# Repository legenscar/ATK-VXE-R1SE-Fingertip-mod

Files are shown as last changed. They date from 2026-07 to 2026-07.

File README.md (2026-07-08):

# ATK-VXE-R1SE-Fingertip-mod
Fingertip Mouse mod for the ATK VXE R1SE+ PCB, featuring a flared pinky rest for a relaxed grip. Read through the whole README before starting.
  
## Things you will need: 
- a suitable screwdriver
- dot skates
- access to a 3D Printer or 3D Printing service
- Sanding paper (recommended but optional)
- Grip tape (recommended but optional)
- patience (recommended but optional)
- lighter (could come in handy)

## Assembly
### 1. Download and print all of the STL files.
I recommend rotating the main buttons 90 degrees if you are printing on a FDM to make sure they feel smooth. Dont forget the supports!



### 2. Disassemble the original mouse
Be careful not to rip the side PCB ribbons. Keep the screws and keep track of their mounting points. The printed mouse shell uses those exact screws with identical mounting points. You will also need to remove the screws for the main buttons.
  
### 3. Assemble the shell
First, screw the PCB onto the base. Dont forget to put the lense underneath first.

Base with PCB

Next, lets take care of the side PCB. For that, mount the side PCB onto the support frame as shown in the picture and insert the side buttons. You may need to sand the "leg" if they dont fit, or glue them into place if they are too lose. If you experience excessive pretravel apply some tape. 

Side PCB assembly

You will need to cut the little "tail" of the side PCB if you dont want it sticking out. I suggest you make that decision after you have assembled the whole mouse. 

Plug in the battery and stick it onto the sensor. Now you can mount the whole support assembly onto the base. First put the side with the buttons in, then the other side. Screw it into place from the bottom.

support in

Last but not least, mount the main buttons and screw them in. Congratulations, youre done! If you experience excessive pretravel you can heat up the "beams" of the main buttons (only if you are using certain plastics like PLA that melt easily and do not give of (very) toxic fumes) and bend them a little. 

Finished mouse

## Notes
- I printed my mouse out of PLA using a Bambu Lab P1S with 0.2mm layer height and standard settings
- Due to the difference in printers and filaments I cannot gurantee that this model works with your setup. I believe in most cases some glue and sandpaper should do the job though.
- The finished mouse might not look 100% like the one in the pictures as I updated some things for better fit.
- This design will probably not work with any other R1 series mice due to the difference in sensors, PCBs (and lenses). Feel free to modify it for those.

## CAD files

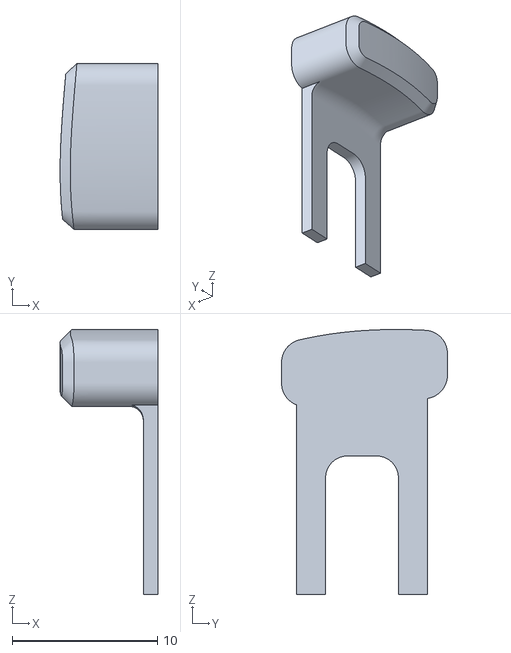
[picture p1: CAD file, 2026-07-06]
STL files/side button 2.stl
6.72 x 11.4 x 18.2

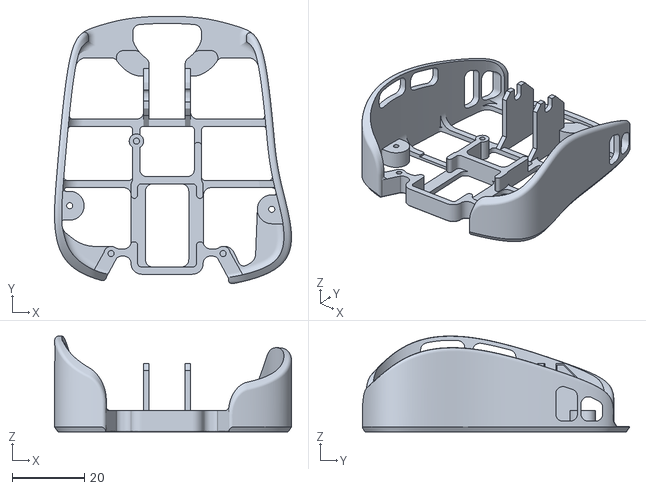
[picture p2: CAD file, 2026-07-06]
STL files/Base.stl
65.7 x 74.1 x 26.6

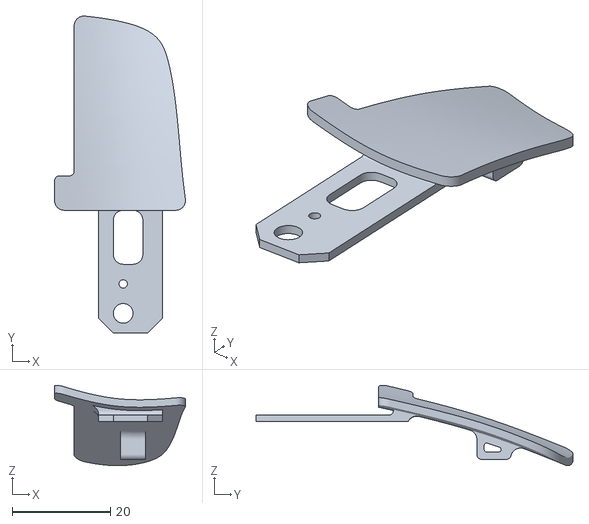
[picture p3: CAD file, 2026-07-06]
STL files/Right mouse button.stl
26.7 x 64.6 x 16.4

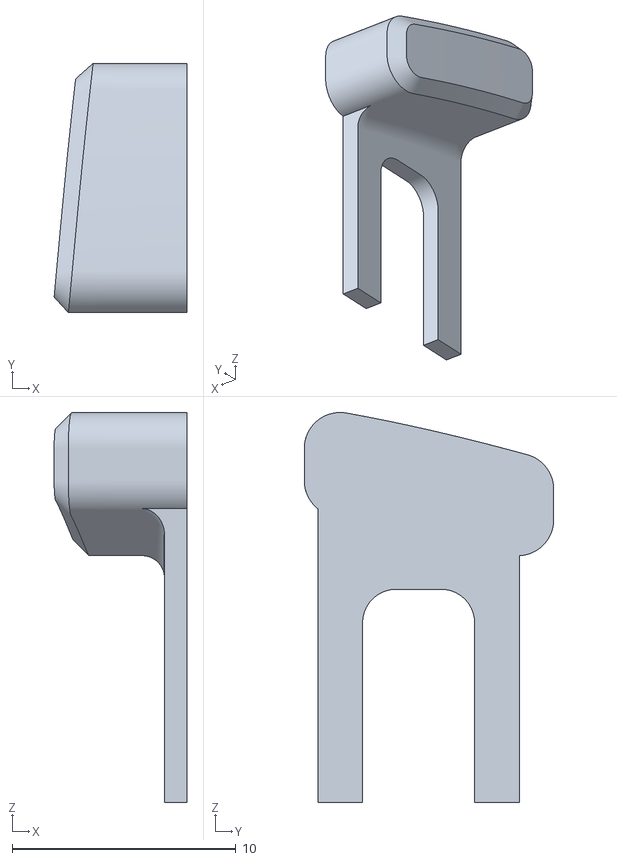
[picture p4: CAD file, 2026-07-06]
STL files/side button 1.stl
5.93 x 11.1 x 17.4

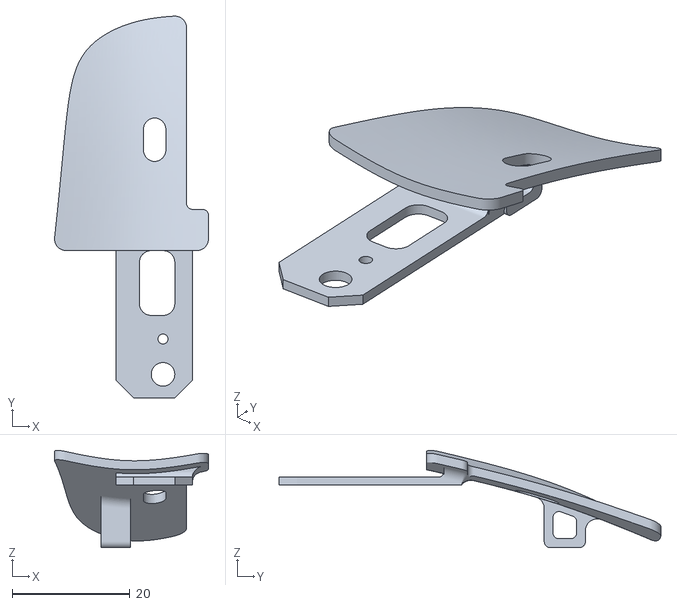
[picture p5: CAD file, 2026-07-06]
STL files/Left mouse button.stl
26.1 x 64.8 x 16.5

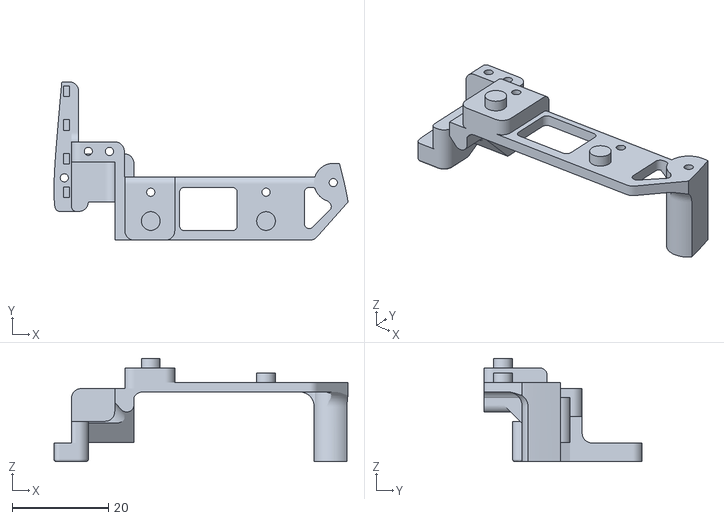
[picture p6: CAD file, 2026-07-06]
STL files/Support.stl
61.2 x 33.0 x 21.5

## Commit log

2026-07-06 Update README with necessary tools for mod
    Added requirements for the fingertip mouse mod.
2026-07-06 Enhance README with assembly steps and materials needed
    Expanded the README with detailed assembly instructions and requirements for the Fingertip Mouse mod.
2026-07-06 Fix image tags in README assembly instructions
    Updated image tags in the assembly section for clarity.
2026-07-06 Update README with detailed mod description
    Enhanced description of the fingertip mouse mod to include details about the flared pinky rest.
2026-07-06 Fix typo in README assembly instructions
    Corrected a typo in the assembly instructions regarding excessive pretravel.
2026-07-06 Update README with assembly image reference
    Added an image reference to the assembly instructions.
2026-07-08 Enhance assembly instructions in README
    Added detailed assembly instructions for the mouse, including steps for mounting the PCB and buttons, and added images for clarity.
